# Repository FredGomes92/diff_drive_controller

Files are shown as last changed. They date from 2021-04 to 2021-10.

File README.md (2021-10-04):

# Autonomous navigation using ROS Navigation Stack

## Parts:

- Raspberry PI
- 2x Arduino nano (one for each motor, the communication with the ROS master is done trough I2C)
- Motor encoders
- Robot chassis
- Boost converter (to provide 6V to the motors)

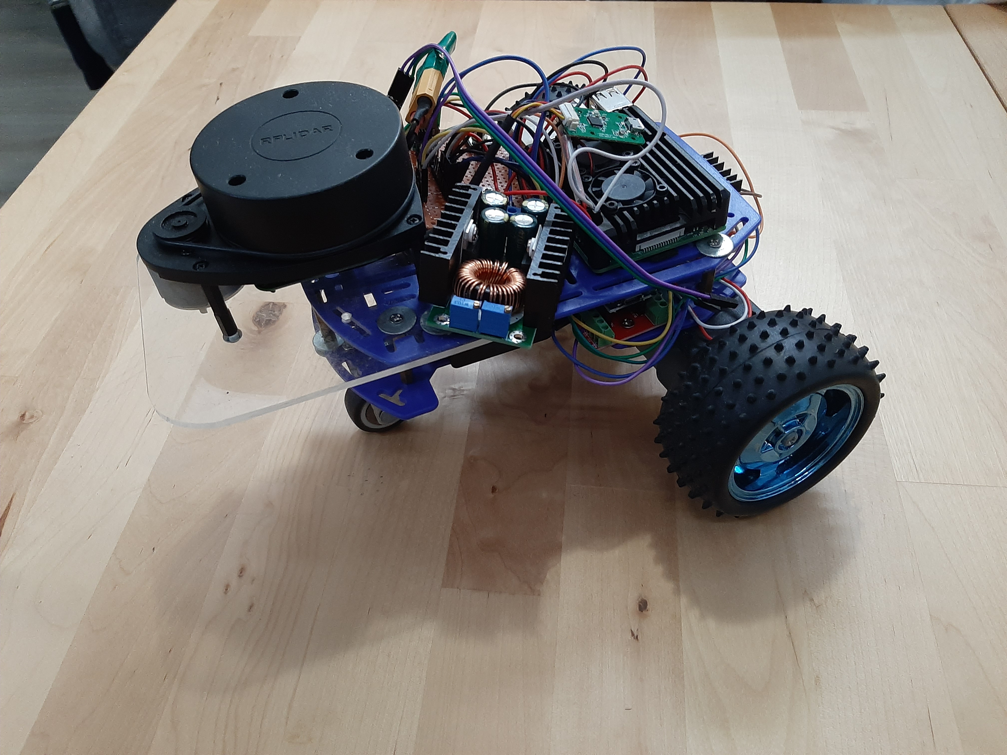
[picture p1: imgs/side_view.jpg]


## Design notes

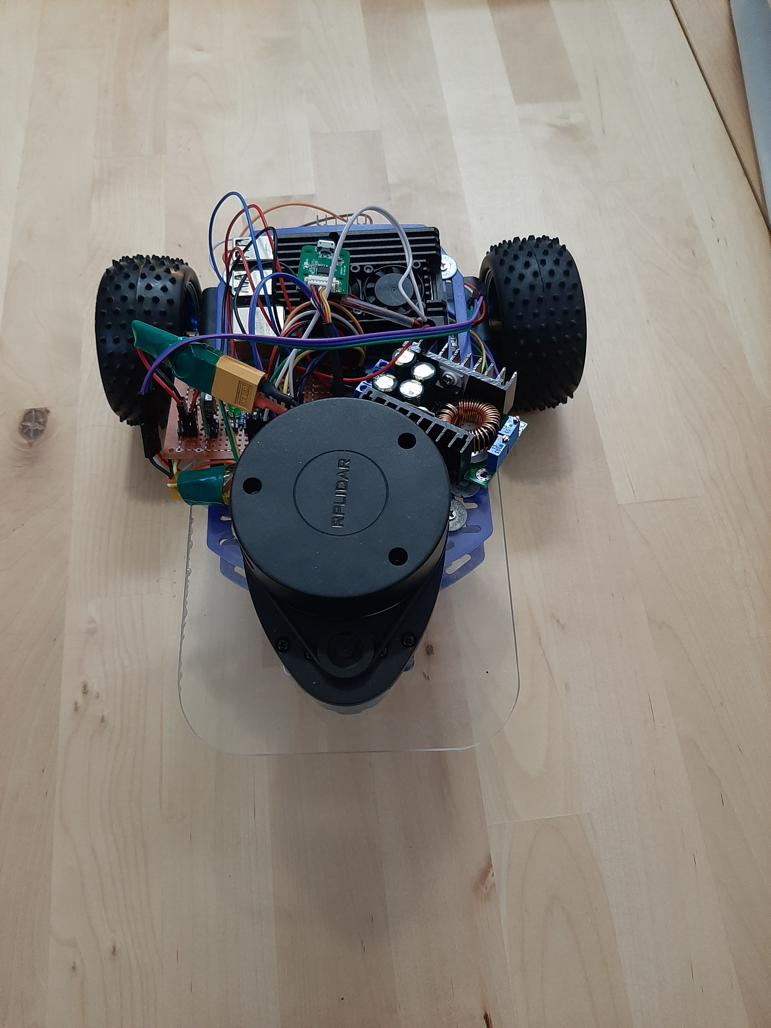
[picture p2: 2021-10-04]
imgs/up_view.jpg

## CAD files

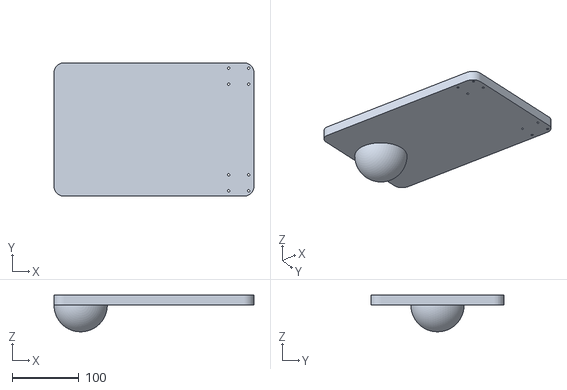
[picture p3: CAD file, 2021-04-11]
stl/chassis.stl
300.0 x 200.0 x 55.0

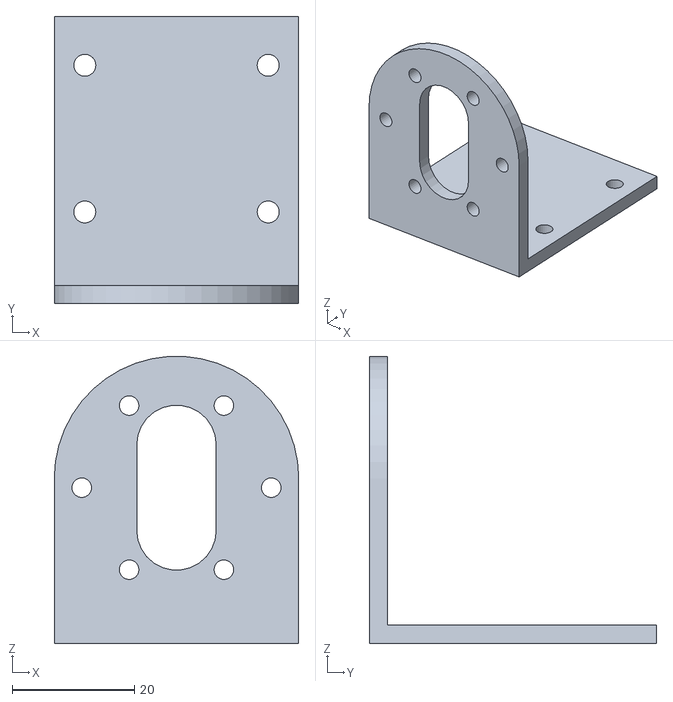
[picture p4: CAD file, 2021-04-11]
stl/flange.stl
40.0 x 47.0 x 47.0

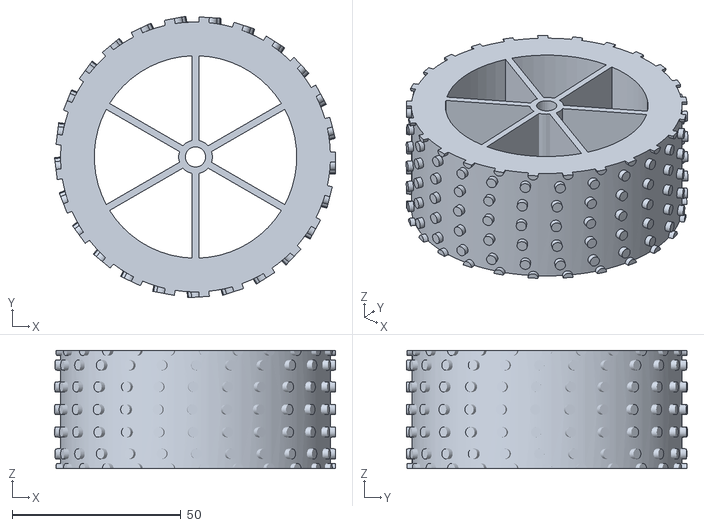
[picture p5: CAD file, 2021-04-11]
stl/wheel.stl
83.3 x 83.4 x 35.0

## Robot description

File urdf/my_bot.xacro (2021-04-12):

<?xml version="1.0" ?>

<robot name="my_bot" xmlns:xacro="https://www.ros.org/wiki/xacro">

    <material name="blue">
	    <color rgba="0 0 0.8 1"/>
    </material>

    <material name="white">
	    <color rgba="1 1 1 1"/>
    </material>

    <material name="grey">
	    <color rgba="0.5 0.5 0.5 1"/>
    </material>

    <material name="black">
      <color rgba="0.0 0.0 0.0 1.0"/>
    </material>

    <material name="green">
        <color rgba="0.0 0.8 0.0 1.0"/>
    </material>

    <link name="base_link">
        <!--<visual>
          <geometry>
             <box size="0.24 0.24 0.001"/>
          </geometry>
          <material name="white"/>
          <origin rpy="0 0 0" xyz="0 0 0.0005"/>
          <material>
            <color rgba="0 0 0.8 1" />
          </material>
        </visual> -->
        <collision>
          <origin rpy="0 0 0" xyz="0 0 0"/>
          <geometry>
            <box size="0.300 0.300 0.015"/>
          </geometry>
        </collision>
    </link>

    <joint name="base_link_joint" type="fixed">
        <origin xyz="0 0 0.0" rpy="0 0 0" />
        <parent link="base_link" />
        <child link="base_plate" />
    </joint>

    <link name="base_plate">
    <visual>
      <origin rpy="0 0 0" xyz="0.0 0.0 0.0"/>
      <geometry>
        <mesh filename="package://my_bot_new/stl/chassis.stl" scale="0.001 0.001 0.001"/>
      </geometry>
      <material name="white"/>
    </visual>
    <collision>
      <origin rpy="0 0 0" xyz="0.0 0.0 0.0" />
      <geometry>
        <mesh filename="package://my_bot_new/stl/chassis.stl" scale="0.001 0.001 0.001" />
      </geometry>
    </collision>
    </link>

    <joint name="right_wheel_joint" type="continuous">
        <origin xyz="0.150 0.100 0.0" rpy="0 0 1.5707963268" />
        <parent link="base_plate" />
        <child link="right_wheel" />
        <axis xyz="1 0 0" />
    </joint>

    <link name="right_wheel">
    <visual>
      <origin xyz="0.0 0.0 0.0" rpy="0 1.5707963268 0" />
      <geometry>
        <mesh filename="package://my_bot_new/stl/wheel.stl" scale="0.001 0.001 0.001"/>
      </geometry>
      <material name="grey"/>
    </visual>
    <collision>
      <origin xyz="0.0 0.0 0.0" rpy="0 1.5707963268 0" />
      <geometry>
        <mesh filename="package://my_bot_new/stl/wheel.stl" scale="0.001 0.001 0.001" />
      </geometry>
    </collision>
    </link>

    <joint name="left_wheel_joint" type="continuous">
        <origin xyz="0.150 -0.100 0.0" rpy="0 0 1.5707963268" />
        <parent link="base_plate" />
        <child link="left_wheel" />
        <axis xyz="1 0 0" />
    </joint>

    <link name="left_wheel">
    <visual>
      <origin xyz="-0.035 0.0 0.0" rpy="0 1.5707963268 0" />

      <geometry>
        <mesh filename="package://my_bot_new/stl/wheel.stl" scale="0.001 0.001 0.001"/>
      </geometry>
      <material name="grey"/>
    </visual>
    <collision>
      <origin xyz="0.0 0.0 0.0" rpy="0 1.5707963268 0" />
      <geometry>
        <mesh filename="package://my_bot_new/stl/wheel.stl" scale="0.001 0.001 0.001" />
      </geometry>
    </collision>
    </link>

    <!-- joint name="laser_joint" type="fixed">
        <origin xyz="0 0.040 0.090" rpy="0 0 1.5708" />
        <parent link="base_plate" />
        <child link="laser" />
    </joint>

    <link name="laser">
    <visual>
      <origin rpy="0 0 -1.5708" xyz="0.084 -0.242 -0.098"/>
      <geometry>
        <mesh filename="package://mobile_robot_autonomous_navigation/stl/RpLidar.stl" scale="0.001 0.001 0.001"/>
      </geometry>
      <material name="blue"/>
    </visual>
    <collision>
      <origin rpy="0 0 0" xyz="0.242 0.084 -0.098" />
      <geometry>
        <mesh filename="package://mobile_robot_autonomous_navigation/stl/RpLidar.stl" scale="0.001 0.001 0.001" />
      </geometry>
    </collision>
    </link>  -->


</robot>

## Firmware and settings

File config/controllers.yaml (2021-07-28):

mobile_robot:

    joints_update:
      type: joint_state_controller/JointStateController
      publish_rate: 50

    mobile_base_controller:
      type        : "diff_drive_controller/DiffDriveController"
      left_wheel  : 'left_wheel_joint'
      right_wheel : 'right_wheel_joint'
      publish_rate: 50.0               # default: 50
      pose_covariance_diagonal : [0.001, 0.001, 1000000.0, 1000000.0, 1000000.0, 1000.0]
      twist_covariance_diagonal: [0.001, 0.001, 1000000.0, 1000000.0, 1000000.0, 1000.0]

      # Wheel separation and diameter. These are both optional.
      # diff_drive_controller will attempt to read either one or both from the
      # URDF if not specified as a parameter
      wheel_separation : 0.180
      wheel_radius : 0.04

      # Wheel separation and radius multipliers
      wheel_separation_multiplier: 1.0 # default: 1.0
      wheel_radius_multiplier    : 1.0 # default: 1.0

      # Velocity commands timeout [s], default 0.5
      cmd_vel_timeout: 0.25

      # Base frame_id
      base_frame_id: "base_link"

      # Velocity and acceleration limits
      # Whenever a min_* is unspecified, default to -max_*
      linear:
        x:
          has_velocity_limits    : true
          max_velocity           : 0.20  # m/s
          min_velocity           : -0.20 # m/s
          has_acceleration_limits: true
          max_acceleration       : 0.025  # m/s^2
          min_acceleration       : -0.025 # m/s^2
          has_jerk_limits        : false
          max_jerk               : 2.0  # m/s^3
      angular:
        z:
          has_velocity_limits    : true
          max_velocity           : 1.0472  # rad/s
          has_acceleration_limits: true
          max_acceleration       : 0.5  # rad/s^2
          has_jerk_limits        : true
          max_jerk               : 1 # rad/s^3

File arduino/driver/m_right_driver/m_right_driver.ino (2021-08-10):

#include <Wire.h>
#include <PID_v1.h>


// M1 motor
#define M1_OUT 10
#define IN1 7 // to define CW and CCW directions
#define IN2 8

// Encoder
#define ENC_PHA 3
#define ENC_PHB 4

#define PPR 330 // pulses per rotation

volatile long enc_pos, last_enc_pos = 0, last_encpos = 0;
unsigned int long lastTime, now;
double outout = 0.0;


// PID
double kp =0.4, ki =0.5 , kd =0.0;
double input = 0, output = 0, setpoint = 0.0;

PID myPID(&input, &output, &setpoint, kp, ki, kd,DIRECT);

float pwm = 0.0;


void setup() {

  pinMode(M1_OUT, OUTPUT);
  pinMode(IN1, OUTPUT);
  pinMode(IN2, OUTPUT);

  // PID
  myPID.SetMode(AUTOMATIC);
  myPID.SetOutputLimits(-255, 255);
  myPID.SetSampleTime(100);


  // I2C
  Wire.begin(11); // configure slave in the address #11
  Wire.onRequest(OnRequestEvent); // data request to slave
  Wire.onReceive(OnReceiveEvent); // data received by slave

  // Encoder A
  pinMode(ENC_PHA, INPUT_PULLUP);
  pinMode(ENC_PHB, INPUT_PULLUP);

  attachInterrupt(digitalPinToInterrupt(ENC_PHA), PulseCnt, RISING);

  TCCR1B = TCCR1B & 0b11111000 | 1;

  Serial.begin(9600);

  Serial.println("I2C save -> ready");

}

void SetPwm(float out)
{
  if (out > 0) //CW
  {
    digitalWrite(IN1, HIGH);
    digitalWrite(IN2, LOW);
  }
  else //CCW
  {
    digitalWrite(IN1, LOW);
    digitalWrite(IN2, HIGH);
  }
  analogWrite(M1_OUT, abs(out));


}

void OnRequestEvent()
{
  int8_t pos;

  pos = ((360.0*(enc_pos - last_encpos)) / 330.0); // change in position -> º ... -1 because the direction is the opposite of the left motor

  //Serial.println("enc_pos: " + String(enc_pos) + " last_enc_pos: " + String(last_enc_pos));
  //Serial.println("Pos: " + String(pos));

  last_encpos = enc_pos;

  Wire.write(pos);


}

void OnReceiveEvent(int c)
{

  uint8_t buff[2];

  for (int i = 0; i < 2; ++i)
  {
    buff[i] =Wire.read();
  }

   // uint8_t a,b;
   // a = Wire.read();
   // b = Wire.read();
   // setpoint= (double)((b<<8)|a);

  setpoint = (double)((buff[0])| (buff[1] << 8));

  //Serial.println((uint8_t)buff[0]);
  //Serial.println((uint8_t)buff[1]);
  //Serial.println("SetPoint(received): " + String(setpoint));


}
void PulseCnt()
{
   if (enc_pos >= (PPR*10) || enc_pos <= -(PPR*10))
      enc_pos = 0;

  if (PINB & 0b0000001) enc_pos ++;  // if (digitalRead(ENC_PHB) == HIGH) enc_pos --;
  else enc_pos --; // if (digitalRead(ENC_PHB) == LOW) enc_pos ++;


  // Serial.println(enc_pos);
}

float vel_to_volt(float vel)
{

  //Y = mx + b --> Y = 0.24566474*x + 155

  float offset = 10;

  if (vel > 0)
    return 0.24566474*vel + 185; //155
  else if (vel < 0)
    return 0.24566474*vel - 185;
  else
    return 0.0;
  
}

void loop() {

    now = millis();
    int td = (now - lastTime);

    float tmp;

    if (td >= 100)
    {
      
        input = (360.0*1000*(enc_pos-last_enc_pos))/(330.0*(now - lastTime)) * -1 ;

        /*if (abs(enc_pos) > abs(last_enc_pos))
        {
          input = tmp;
        }
        if (abs(enc_pos) == abs(last_enc_pos))
        {
          input = 0.0;
        }*/

        //Serial.println("enc_pos: " + String(enc_pos) + " enc_last_pos: " + String(last_enc_pos) + " Vel: " + String(input));


        lastTime = now;
        last_enc_pos = enc_pos;

        myPID.Compute();                                    // calculate new output

        if (setpoint > 500) setpoint = 0.0;
        if (setpoint == 0) output = 0;
    
        Serial.println("setpoint: " + String(setpoint) + " input: " + String(input) + " output: " + String(output));
    
        SetPwm(output);            // drive L298N H-Bridge module

    }
    
 }
  

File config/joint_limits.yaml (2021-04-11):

joint_limits:
    right_wheel_joint:
      has_position_limits: false
      min_position: 0
      max_position: 0
      has_velocity_limits: true
      max_velocity: 4.5
      min_velocity: -4.5
      has_acceleration_limits: false
      max_acceleration: 0.0
      has_jerk_limits: false
      max_jerk: 0
      has_effort_limits: false
      max_effort: 0
      min_effort: 0

    left_wheel_joint:
      has_position_limits: false
      min_position: 0
      max_position: 0
      has_velocity_limits: true
      max_velocity: 4.5
      min_velocity: -4.5
      has_acceleration_limits: false
      max_acceleration: 0.0
      has_jerk_limits: false
      max_jerk: 0
      has_effort_limits: false
      max_effort: 0
      min_effort: 0

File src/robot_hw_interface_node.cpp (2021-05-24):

#include "diff_drive_controller/robot_hw_interface_node.h"

MyRobotHWInterface::MyRobotHWInterface(ros::NodeHandle &nh) : nh_(nh)
{
    init();

    controller_manager_.reset(new controller_manager::ControllerManager(this, nh_));
    loop_hz_ = 10;

    ros::Duration update_freq = ros::Duration(1.0/loop_hz_);

    async_time = nh_.createTimer(update_freq, &MyRobotHWInterface::update, this);


}
MyRobotHWInterface::~MyRobotHWInterface(){}

void MyRobotHWInterface::init()
{
    for ( int i = 0; i < 2; ++i)
    {
        // create a joint interface
        hardware_interface::JointStateHandle jointStateHandle(joint_name_[i], &joint_position_[i], &joint_velocity_[i], &joint_effort_[i]);
        joint_state_interface_.registerHandle(jointStateHandle);

        // create a velocity joint interface
        hardware_interface::JointHandle jointVelocityHandle(jointStateHandle, &joint_velocity_command_[i]);
        velocity_joint_interface_.registerHandle(jointVelocityHandle);

        // create a joint limit interface
        joint_limits_interface::JointLimits limits;
        joint_limits_interface::getJointLimits(joint_name_[i], nh_, limits);
        joint_limits_interface::VelocityJointSaturationHandle jointlimitsHandle(jointVelocityHandle, limits);
        velocity_joint_saturation_interface_.registerHandle(jointlimitsHandle);

    }

    // Register all joints interfaces
    registerInterface(&joint_state_interface_);
    registerInterface(&velocity_joint_interface_);
    registerInterface(&velocity_joint_saturation_interface_);

}
void MyRobotHWInterface::update(const ros::TimerEvent& te)
{

    ROS_INFO("update");

    elapsed_time_ = ros::Duration(te.current_real - te.last_real);
    read();
    controller_manager_->update(ros::Time::now(), elapsed_time_);
    write(elapsed_time_);

}
void MyRobotHWInterface::read()
{
    uint8_t rbuff[1];
    int x;

    right_motor.readBytes(rbuff,1);
    x=(int8_t)rbuff[0];
    right_motor_pos += angles::from_degrees((double)x);
    joint_position_[0]=right_motor_pos;

    left_motor.readBytes(rbuff,1);
    x=(int8_t)rbuff[0];
    left_motor_pos += angles::from_degrees((double)x);
    joint_position_[1]=left_motor_pos;

    //ROS_INFO("joint_psition[0]: %f, joint_psition[01]: %f", joint_position_[0], joint_position_[1]);



}
void MyRobotHWInterface::write(ros::Duration elapsed_time)
{

    velocity_joint_saturation_interface_.enforceLimits(elapsed_time);

    uint8_t wbuff[2];

    int velocity,result;

    velocity=(int)angles::to_degrees(joint_velocity_command_[0]);
	wbuff[0]=velocity;
    wbuff[1]=velocity >> 8;

    ROS_INFO("joint_velocity_command_[0]=%.2f velocity=%d  wbuff[0]=%d wbuff[1]=%d", joint_velocity_command_[0],velocity,wbuff[0],wbuff[1]);

    if(right_prev_cmd!=velocity)
    {
	    result = right_motor.writeData(wbuff,2);

        ROS_INFO("Writen successfully result=%d", result);
	    right_prev_cmd = velocity;
    }

    velocity=(int)angles::to_degrees(joint_velocity_command_[1]);
	wbuff[0]=velocity;
    wbuff[1]=velocity >> 8;

    ROS_INFO("joint_velocity_command_[1]=%.2f velocity=%d  wbuff[0]=%d wbuff[1]=%d", joint_velocity_command_[0],velocity,wbuff[0],wbuff[1]);

    if(lef_prev_cmd!=velocity)
    {
	    result = left_motor.writeData(wbuff,2);

        ROS_INFO("Writen successfully result=%d", result);
	    lef_prev_cmd = velocity;
    }

}

int main(int argc, char ** argv)
{
    ros::init(argc, argv, "single_joint_interface");
    ros::NodeHandle nh;

    ros::MultiThreadedSpinner spinner(2); // Multiple threads for controller service callback and for the Service client callback used to get the feedback from ardiuno
    MyRobotHWInterface my_bot(nh);
    //spinner.start();
    spinner.spin();

    return 0;
}

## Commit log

2021-04-05 add hw_interface and i2c comm
    [controllers.yaml, joint_limits.yaml]
2021-04-11 update rpi
    [joint_limits.yaml]
2021-04-12 update controller
    [controllers.yaml, my_bot.urdf.xacro, my_bot.xacro]
2021-04-15 add the motor_left driver
2021-04-19 working: fix bugs in driver
    [m_right_driver.ino]
2021-05-24 add second motor to diff drive
2021-05-24 update motor right and motor left controllers
2021-07-28 modify speeds limit
    [controllers.yaml]
2021-08-02 adjust PID parameteres
2021-08-10 Update PID parameteres
